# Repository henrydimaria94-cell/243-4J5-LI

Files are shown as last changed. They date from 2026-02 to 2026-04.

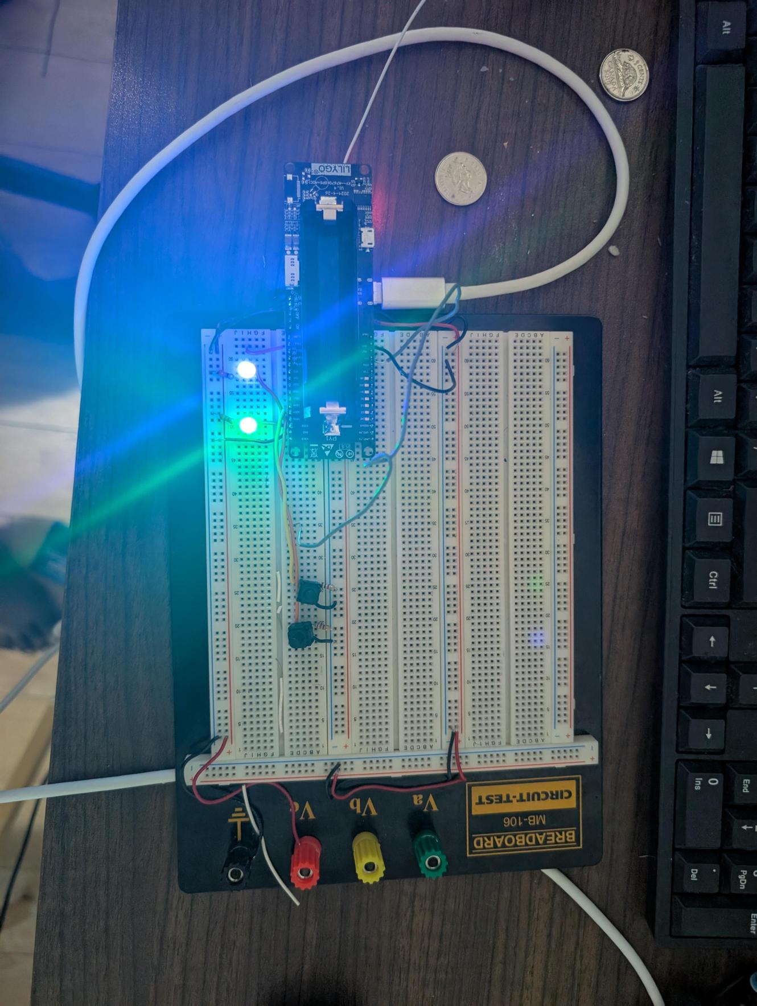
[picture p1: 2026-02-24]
labo/Labo-02/Média (19).jpg

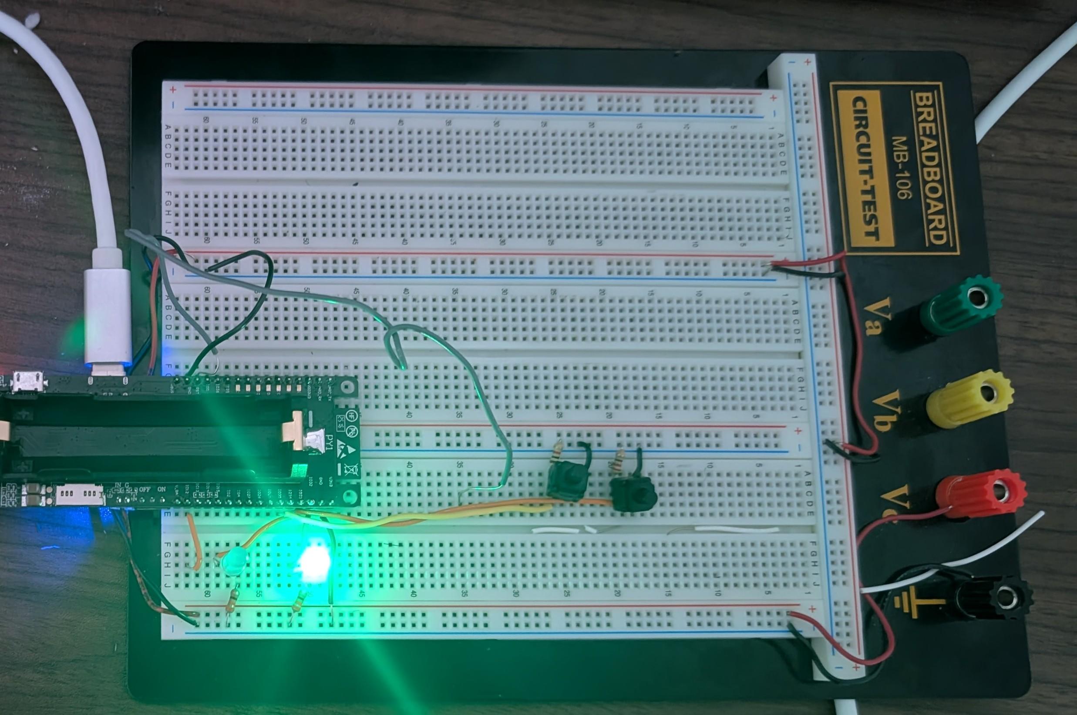
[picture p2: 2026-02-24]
labo/Labo-02/Média (20).jpg

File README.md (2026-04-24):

# Labo 04 — Communication LoRa avec LilyGo T-Beam Supreme

Communication bidirectionnelle LoRa entre deux modules LilyGo T-Beam Supreme S3.  
Le transmetteur envoie la valeur d'un potentiomètre ; le récepteur interroge un LLM via l'API Groq, renvoie la réponse par LoRa et publie les métriques sur un broker MQTT.

## Architecture du système

```
[Transmetteur]                              [Récepteur]
  Potentiomètre                               SX1262 (LoRa)
       │                                           │
  SX1262 (LoRa) ──── 915 MHz / SF9 ──────►  WiFi → API Groq (LLM)
       │                                           │
  OLED SH1106   ◄──── réponse texte ────────  MQTT WebSocket TLS
  LED GPIO 43                                 LED GPIO 43
```

## Matériel requis

| Composant | Quantité |
|---|---|
| LilyGo T-Beam Supreme S3 (SX1262) | 2 |
| Potentiomètre (branché sur GPIO 2) | 1 |

## Structure du projet

```
Labo-04-TP/
├── transmitter/
│   ├── transmitter.ino       # Sketch émetteur LoRa
│   ├── LoRaBoards.h/.cpp     # Abstraction matérielle LilyGo
│   └── utilities.h           # Définitions des broches
│
├── receiver/
│   ├── receiver.ino          # Sketch récepteur LoRa + LLM + MQTT
│   ├── config.example.h      # ← Modèle de configuration
│   ├── config.h              # ← À créer (ignoré par Git)
│   ├── LoRaBoards.h/.cpp
│   └── utilities.h
│
└── llm-t-beam-supreme/       # Sketch autonome test LLM sans LoRa
```

## Installation

### 1. Cloner le dépôt

```bash
git clone <url-du-repo>
```

### 2. Créer le fichier de configuration

```bash
cp receiver/config.example.h receiver/config.h
```

Ouvrez `receiver/config.h` et remplissez vos valeurs :

```cpp
// WiFi personnel
#define WIFI_SECURITY_WPA2_PERSONAL
const char* WIFI_SSID     = "MonReseau";
const char* WIFI_PASSWORD = "MonMotDePasse";

// API Groq — https://console.groq.com
const char* API_KEY = "gsk_...";

// MQTT
const char* MQTT_BROKER = "votre-broker.exemple.com";
const char* MQTT_USER   = "utilisateur";
const char* MQTT_PASS   = "motdepasse";

// Topics — adaptez le préfixe
const char* MQTT_TOPIC_POT     = "prenom-nom/pot";
const char* MQTT_TOPIC_REPONSE = "prenom-nom/reponse";
const char* MQTT_TOPIC_RSSI    = "prenom-nom/rssi";
const char* MQTT_TOPIC_SNR     = "prenom-nom/snr";
```

> `config.h` est listé dans `.gitignore` — il ne sera jamais commité.

### 3. Librairies Arduino requises

Installez via le gestionnaire de librairies Arduino IDE :

| Librairie | Auteur |
|---|---|
| ArduinoJson | Benoit Blanchon |
| U8g2 | olikraus |
| XPowersLib | Lewis He |
| RadioLib | jgromes |
| PubSubClient | Nick O'Leary |

### 4. Sélectionner la carte

**Tools → Board → ESP32S3 Dev Module**

| Paramètre | Valeur |
|---|---|
| USB CDC On Boot | Enabled |
| Flash Size | 16MB |
| PSRAM | OPI PSRAM |

### 5. Téléverser

1. Téléverser `transmitter/transmitter.ino` sur le premier T-Beam.
2. Téléverser `receiver/receiver.ino` sur le second T-Beam.

## Paramètres LoRa

| Paramètre | Valeur |
|---|---|
| Fréquence | 915.0 MHz |
| Bande passante | 125 kHz |
| Spreading Factor | 9 |
| Coding Rate | 7 |
| Sync Word | 0x12 |
| Puissance TX | 14 dBm |
| Préambule | 16 |
| CRC | Activé |

## Format des messages LoRa

**Transmetteur → Récepteur**
```json
{ "pot": 2048 }
```

**Récepteur → Transmetteur**
```
Texte brut — réponse du LLM (max 40 caractères)
```

## Topics MQTT publiés par le récepteur

| Topic | Contenu |
|---|---|
| `{prefix}/pot` | Valeur du potentiomètre (0–4095) |
| `{prefix}/reponse` | Réponse du LLM |
| `{prefix}/rssi` | RSSI LoRa (dBm) |
| `{prefix}/snr` | SNR LoRa (dB) |

## Comportement du transmetteur

- Lecture continue du potentiomètre (GPIO 2, ADC 12 bits, 0–4095)
- Envoi si valeur stable ≥ 400 ms **et** variation > 80 unités depuis le dernier envoi
- Délai minimal de 3 secondes entre deux transmissions
- Attente de la réponse du récepteur (timeout 30 s)
- LED GPIO 43 : 3 flashs rapides à l'envoi, puis fixe selon l'effort (HIGH si pot > 2048)

## Comportement du récepteur

- Réception LoRa par interruption (DIO1)
- Appel API Groq dès réception d'un paquet valide
- Retransmission de la réponse texte au transmetteur
- Publication MQTT sur 4 topics
- Affichage OLED avec retour écran veille après 10 secondes
- LED GPIO 43 : allumée pendant le traitement LLM

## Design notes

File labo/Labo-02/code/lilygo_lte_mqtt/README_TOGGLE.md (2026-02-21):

# Guide : Synchronisation ESP32 ↔ Interface Python

## 🔄 Problème résolu

L'interface Python n'affichait pas les changements d'état des LEDs causés par les boutons physiques car elle ne s'abonnait pas aux topics d'état.

## ✅ Modifications apportées

### 1. Code Arduino (`lilygo_lte_mqtt_toggle.ino`)

#### Nouveaux topics MQTT
```cpp
char LED1_STATE_TOPIC[50];  // {device_id}/led/1/state
char LED2_STATE_TOPIC[50];  // {device_id}/led/2/state
```

#### Variables d'état avec debounce
```cpp
bool led1State = false;
bool led2State = false;
unsigned long lastButton1Press = 0;
unsigned long lastButton2Press = 0;
const unsigned long DEBOUNCE_DELAY = 200;  // 200ms
```

#### Fonction de toggle
```cpp
void checkButtonsForToggle() {
    unsigned long now = millis();
    
    // Bouton 1
    if (digitalRead(BUTTON1_PIN) == LOW) {
        if (now - lastButton1Press > DEBOUNCE_DELAY) {
            lastButton1Press = now;
            led1State = !led1State;
            digitalWrite(LED1_PIN, led1State ? HIGH : LOW);
            const char* state = led1State ? "ON" : "OFF";
            mqttClient.publish(LED1_STATE_TOPIC, state);
        }
    }
    
    // Bouton 2 (même logique)
}
```

### 2. Interface Python (`touch_ui_mqtt.py`)

#### Ajout des topics d'état
```python
self.led1_state_topic = f"{device_id}/led/1/state"
self.led2_state_topic = f"{device_id}/led/2/state"
```

#### Abonnement aux topics d'état
```python
def _on_mqtt_connect(self, client, userdata, flags, rc):
    # ... code existant ...
    client.subscribe(self.led1_state_topic)
    client.subscribe(self.led2_state_topic)
```

#### Synchronisation de l'état
```python
def _on_mqtt_message(self, client, userdata, msg):
    topic = msg.topic
    payload = msg.payload.decode('utf-8', errors='ignore')
    
    # Synchroniser LED1
    if topic == self.led1_state_topic:
        self.led1_state = (payload == "ON")
        self.status_message = f"LED ROUGE: {payload} (ESP32)"
    
    # Synchroniser LED2
    elif topic == self.led2_state_topic:
        self.led2_state = (payload == "ON")
        self.status_message = f"LED VERTE: {payload} (ESP32)"
```

## 📊 Architecture de communication

### Flux de données

```
┌─────────────────┐                    ┌──────────────────┐
│   ESP32 LilyGO  │                    │  Interface Python│
│                 │                    │                  │
│  Bouton 1 (34) ─┼──┐                 │                  │
│  Bouton 2 (35) ─┼──┤                 │                  │
│                 │  │                 │                  │
│  LED 1 (32)  ◄──┼──┤                 │                  │
│  LED 2 (33)  ◄──┼──┘                 │                  │
└────────┬────────┘                    └────────┬─────────┘
         │                                      │
         │  MQTT via WSS (Port 443)            │
         │  ════════════════════════            │
         │                                      │
         ├──► {id}/led/1/state ────────────────┤
         │         (ON/OFF)                     │
         │                                      │
         ├──► {id}/led/2/state ────────────────┤
         │         (ON/OFF)                     │
         │                                      │
         │◄──── {id}/led/1/set ─────────────────┤
         │         (ON/OFF)                     │
         │                                      │
         │◄──── {id}/led/2/set ─────────────────┤
                   (ON/OFF)
```

### Topics MQTT

| Topic | Publisher | Subscriber | Payload | Description |
|---|---|---|---|---|
| `{id}/led/1/set` | Python | ESP32 | `ON` / `OFF` | Commande depuis interface |
| `{id}/led/2/set` | Python | ESP32 | `ON` / `OFF` | Commande depuis interface |
| `{id}/led/1/state` | ESP32 | Python | `ON` / `OFF` | État actuel LED1 |
| `{id}/led/2/state` | ESP32 | Python | `ON` / `OFF` | État actuel LED2 |
| `{id}/button/1/state` | ESP32 | Python | `PRESSED` / `RELEASED` | Événement bouton 1 |
| `{id}/button/2/state` | ESP32 | Python | `PRESSED` / `RELEASED` | Événement bouton 2 |

## 🧪 Test de fonctionnement

### Scénario 1 : Toggle depuis bouton physique
1. **Action** : Appuyer sur Bouton 1 (GPIO 34)
2. **ESP32** :
   - Toggle `led1State` (OFF → ON)
   - Allume LED1 physiquement
   - Publie `{id}/led/1/state = ON`
3. **Interface Python** :
   - Reçoit le message MQTT
   - Met à jour `self.led1_state = True`
   - Affiche "ON" en gros caractères
   - Status : "LED ROUGE: ON (ESP32)"

### Scénario 2 : Commande depuis interface
1. **Action** : Toucher "LED VERTE" dans l'interface
2. **Interface Python** :
   - Toggle `self.led2_state` (OFF → ON)
   - Publie `{id}/led/2/set = ON`
3. **ESP32** :
   - Reçoit la commande
   - Allume LED2 physiquement
   - Met à jour `led2State = true`
   - Confirme avec `{id}/led/2/state = ON`
4. **Interface Python** :
   - Reçoit la confirmation
   - État déjà à jour (pas de changement visuel)

### Scénario 3 : Synchronisation au démarrage
1. **ESP32** démarre avec LEDs éteintes
2. **ESP32** se connecte à MQTT et publie :
   - `{id}/led/1/state = OFF`
   - `{id}/led/2/state = OFF`
3. **Interface Python** reçoit les messages et synchronise l'affichage

## 🐛 Vérification du bon fonctionnement

### Dans le moniteur série de l'ESP32
```
[BTN1 TOGGLE] LED1 -> ON
[BTN1 TOGGLE] LED1 -> OFF
[BTN2 TOGGLE] LED2 -> ON
[LED1] Allumee (ROUGE) - commande distante
```

### Dans l'interface Python (zone MQTT DEBUG)
```
✓ Connecté au broker MQTT
✓ Abonné à esp32-XXXX/led/1/state
✓ Abonné à esp32-XXXX/led/2/state
← esp32-XXXX/led/1/state: ON
🔴 LED1 mise à jour: ON
→ esp32-XXXX/led/2/set: OFF
← esp32-XXXX/led/2/state: OFF
🟢 LED2 mise à jour: OFF
```

## 🔧 Configuration requise

### Fichier `auth.h` (ESP32)
```cpp
#define MQTT_BROKER "mqtt.edxo.ca"
#define MQTT_CLIENT_ID "esp32-XXXX"  // Votre ID unique
#define MQTT_USER "esp_user"
#define MQTT_PASS "votre_mot_de_passe"
#define APN "votre_apn"
// ...
```

### Fichier `mqtt_config.py` (Python)
```python
MQTT_CONFIG = {
    "broker": "mqtt.edxo.ca",
    "port": 443,
    "device_id": "esp32-XXXX",  # Doit correspondre à MQTT_CLIENT_ID
    "username": "esp_user",
    "password": "votre_mot_de_passe"
}
```

## ⚠️ Points d'attention

1. **Device ID identique** : Le `device_id` dans Python doit correspondre au `MQTT_CLIENT_ID` de l'ESP32
2. **Connexion WSS** : Port 443 avec WebSocket Secure
3. **Debounce** : 200ms pour éviter les rebonds des boutons
4. **Pull-up interne** : Les boutons utilisent `INPUT_PULLUP` (LOW = pressé)
5. **Synchronisation bidirectionnelle** : Les deux interfaces publient ET s'abonnent aux états

## 📝 Fichiers modifiés

- ✅ `lilygo_lte_mqtt_toggle.ino` (nouveau fichier)
- ✅ `touch_ui_mqtt.py` (modifications)
- ✅ Code original `lilygo_lte_mqtt.ino` (conservé intact)

## 🚀 Démarrage rapide

1. **Téléverser** `lilygo_lte_mqtt_toggle.ino` sur l'ESP32
2. **Vérifier** les connexions :
   - Bouton 1 → GPIO 34
   - Bouton 2 → GPIO 35
   - LED 1 → GPIO 32 (rouge)
   - LED 2 → GPIO 33 (verte)
3. **Lancer** l'interface Python :
   ```bash
   cd /home/henridumont/243-4J5-LI/labo/Labo-02/led-control
   python3 touch_ui_mqtt.py
   ```
4. **Tester** :
   - Appuyer sur les boutons physiques
   - Toucher l'écran pour contrôler les LEDs
   - Observer la synchronisation dans les deux sens

## 🎯 Résultat attendu

- ✅ Appui sur bouton physique → LED change + Interface se met à jour
- ✅ Touch sur interface → LED change + État confirmé par ESP32
- ✅ Messages MQTT visibles dans la zone DEBUG
- ✅ Pas de désynchronisation entre ESP32 et Python

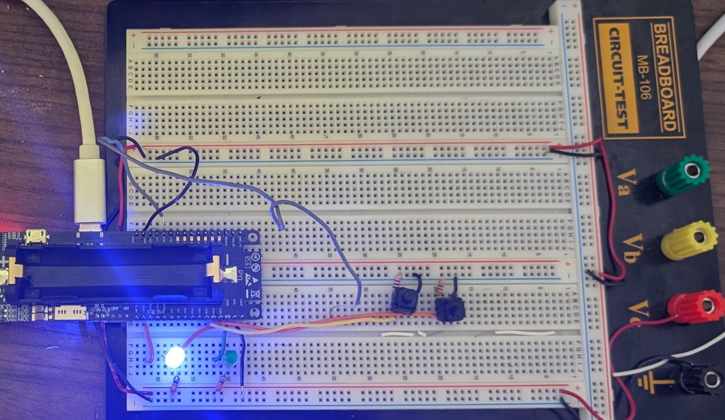
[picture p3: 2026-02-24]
labo/Labo-02/Média (18).jpg

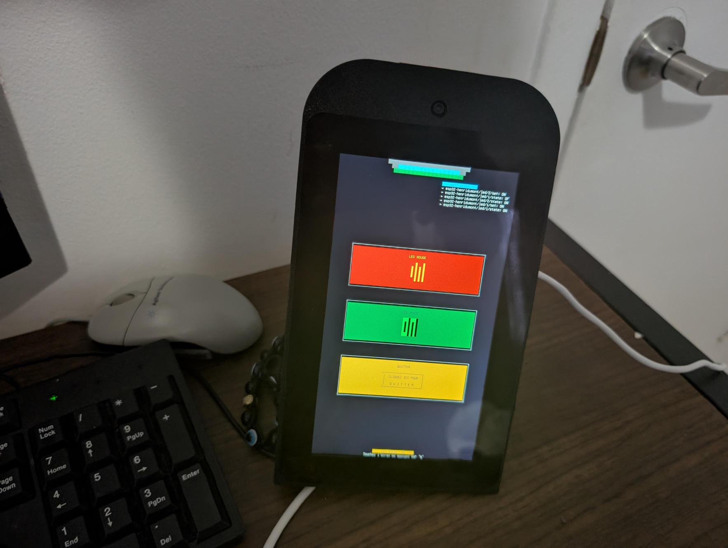
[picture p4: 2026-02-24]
labo/Labo-02/Média (17).jpg

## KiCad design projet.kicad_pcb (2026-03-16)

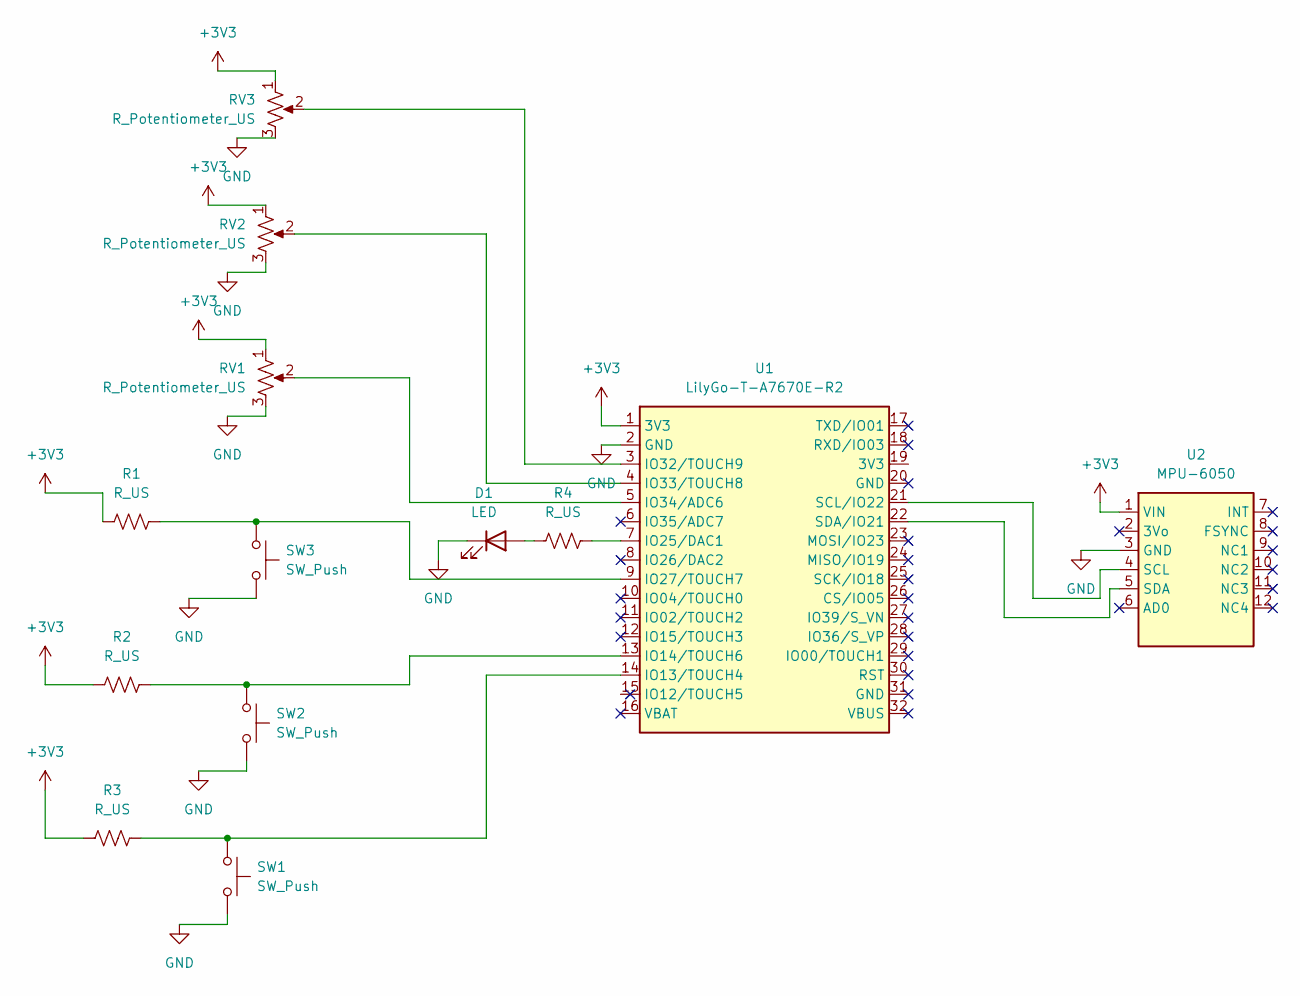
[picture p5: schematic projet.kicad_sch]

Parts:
D1: LED; LED_D5.0mm
R1, R2, R3, R4: R_US; R_Axial_DIN0207_L6.3mm_D2.5mm_P7.62mm_Horizontal
RV1, RV2, RV3: R_Potentiometer_US; Potentiometer_Bourns_3386P_Vertical
SW1, SW2, SW3: SW_Push; SW_B3WN-600x_OMR
U1: LilyGo-T-A7670E-R2; LilyGO_T-A7670E-R2
U2: MPU-6050; MPU-6050_Breakout

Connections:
+3V3: R1.1, R2.1, R3.1, RV1.1, RV2.1, RV3.1, U1.1 (3V3), U2.1 (VIN)
GND: D1.1 (K), RV1.3, RV2.3, RV3.3, SW1.2, SW2.2, SW3.2, U1.2 (GND), U2.3 (GND)
unnamed: D1.2 (A), R4.1
unnamed: R3.2, SW1.1, U1.14 (IO13/TOUCH4)
unnamed: R2.2, SW2.1, U1.13 (IO14/TOUCH6)
unnamed: R4.2, U1.7 (IO25/DAC1)
unnamed: R1.2, SW3.1, U1.9 (IO27/TOUCH7)
unnamed: RV3.2, U1.3 (IO32/TOUCH9)
unnamed: RV2.2, U1.4 (IO33/TOUCH8)
unnamed: RV1.2, U1.5 (IO34/ADC6)
unnamed: U1.21 (SCL/IO22), U2.4 (SCL)
unnamed: U1.22 (SDA/IO21), U2.5 (SDA)

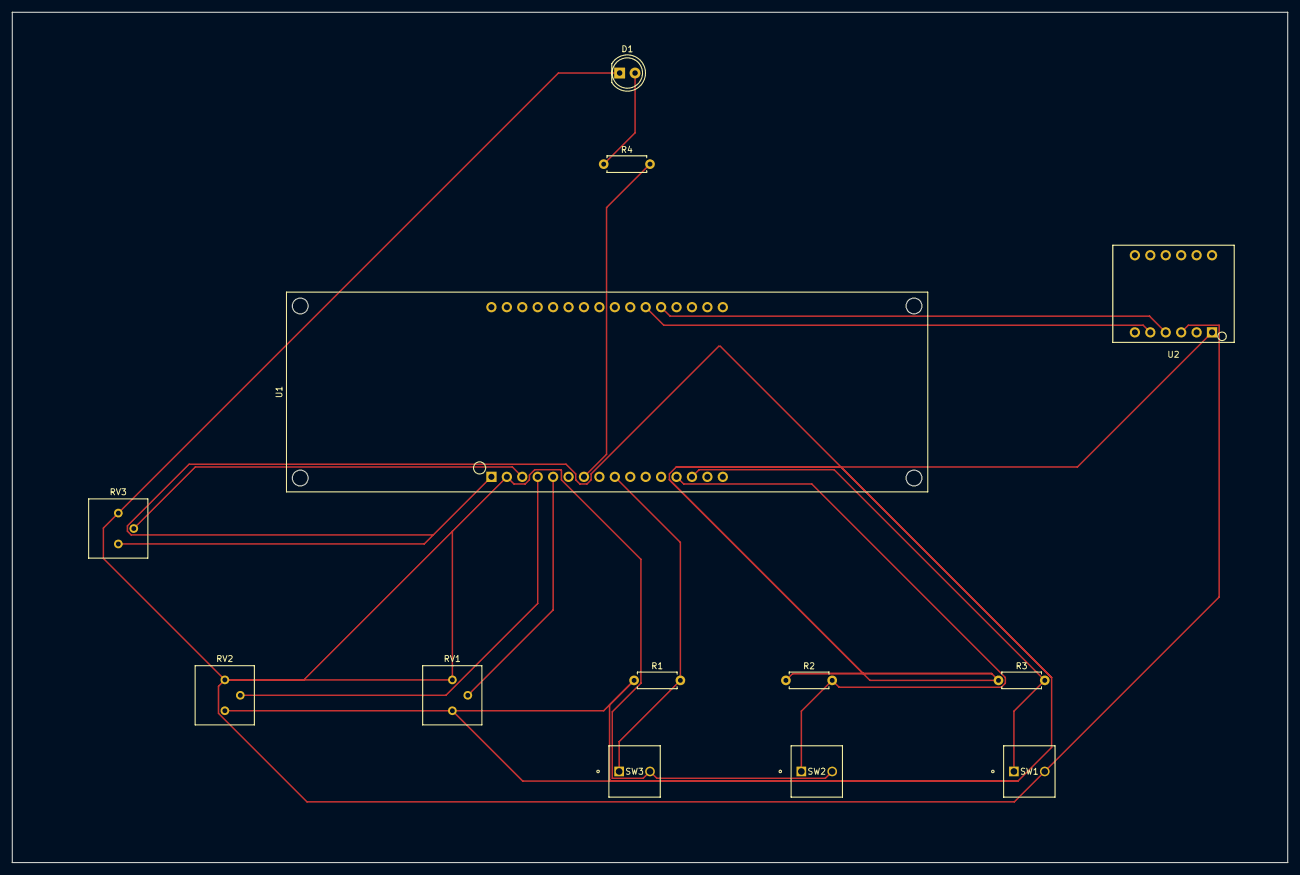
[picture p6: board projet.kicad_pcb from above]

Board: 2 copper layers, 210.0 x 140.0 mm, 13 parts (0 on the bottom side), 12 nets.

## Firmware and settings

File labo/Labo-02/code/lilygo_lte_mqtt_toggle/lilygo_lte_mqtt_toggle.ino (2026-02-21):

// LilyGO T-SIM A7670G - Version avec TOGGLE des LEDs par boutons
// Basé sur lilygo_lte_mqtt.ino avec ajout de la fonctionnalité de toggle
// Les boutons permettent maintenant de basculer l'état des LEDs localement
// et de publier l'état sur MQTT

#define TINY_GSM_MODEM_SIM7600
#define TINY_GSM_RX_BUFFER 1024

#include <TinyGsmClient.h>
#include <PubSubClient.h>

// ESP_SSLClient configuration
#define ENABLE_DEBUG
#define ENABLE_ERROR_STRING
#define DEBUG_PORT Serial
#define SSLCLIENT_INSECURE_ONLY

#include <ESP_SSLClient.h>
#include <mbedtls/base64.h>

#include "auth.h"

// ====== CONFIG MODEM A7670G ======
#define MODEM_TX 26
#define MODEM_RX 27
#define MODEM_PWRKEY 4
#define MODEM_DTR 12
#define MODEM_RI 13
#define MODEM_FLIGHT 25
#define MODEM_STATUS 0

#define SD_MISO 2
#define SD_MOSI 15
#define SD_SCLK 14
#define SD_CS 13

// ====== CONFIG MQTT/WSS ======
const char* MQTT_HOST = MQTT_BROKER;
const int   MQTT_WSS_PORT = 443;
const char* MQTT_PATH = "/";

// Topics MQTT
char BUTTON1_STATE_TOPIC[50];  // {device_id}/button/1/state (PRESSED/RELEASED)
char BUTTON2_STATE_TOPIC[50];  // {device_id}/button/2/state (PRESSED/RELEASED)
char LED1_SET_TOPIC[50];       // {device_id}/led/1/set (commandes depuis l'interface)
char LED2_SET_TOPIC[50];       // {device_id}/led/2/set (commandes depuis l'interface)
char LED1_STATE_TOPIC[50];     // {device_id}/led/1/state (état ON/OFF publié par ESP32)
char LED2_STATE_TOPIC[50];     // {device_id}/led/2/state (état ON/OFF publié par ESP32)

// --- Configuration des broches (Pins) ---
const int LED1_PIN = 32;
const int LED2_PIN = 33;
const int BUTTON1_PIN = 34;
const int BUTTON2_PIN = 35;

// ====== VARIABLES GLOBALES POUR LE TOGGLE ======
bool led1State = false;              // État actuel de LED1
bool led2State = false;              // État actuel de LED2
unsigned long lastButton1Press = 0; // Timestamp du dernier appui bouton 1
unsigned long lastButton2Press = 0; // Timestamp du dernier appui bouton 2
const unsigned long DEBOUNCE_DELAY = 200;  // Délai anti-rebond (200ms)

// Serial pour le modem
HardwareSerial SerialAT(1);

// ============================================================================
// CLASSE WRAPPER WEBSOCKET POUR PUBSUBCLIENT
// ============================================================================

class WebSocketClient : public Client {
private:
  ESP_SSLClient* _sslClient;
  bool _wsConnected;

  // Buffer pour les données reçues
  uint8_t _rxBuffer[512];
  size_t _rxBufferLen;
  size_t _rxBufferPos;

  String generateWebSocketKey() {
    uint8_t key[16];
    for(int i = 0; i < 16; i++) {
      key[i] = random(0, 256);
    }
    size_t olen;
    unsigned char output[64];
    mbedtls_base64_encode(output, sizeof(output), &olen, key, 16);
    return String((char*)output);
  }

  bool readWebSocketFrame() {
    if (!_sslClient->available()) return false;

    uint8_t byte1 = _sslClient->read();
    if (!_sslClient->available()) return false;
    uint8_t byte2 = _sslClient->read();

    uint8_t opcode = byte1 & 0x0F;
    bool masked = (byte2 & 0x80) != 0;
    size_t payloadLen = byte2 & 0x7F;

    if (payloadLen == 126) {
      if (_sslClient->available() < 2) return false;
      payloadLen = (_sslClient->read() << 8) | _sslClient->read();
    } else if (payloadLen == 127) {
      if (_sslClient->available() < 8) return false;
      payloadLen = 0;
      for(int i = 0; i < 8; i++) {
        payloadLen = (payloadLen << 8) | _sslClient->read();
      }
    }

    uint8_t mask[4] = {0};
    if (masked) {
      if (_sslClient->available() < 4) return false;
      for(int i = 0; i < 4; i++) {
        mask[i] = _sslClient->read();
      }
    }

    if (opcode == 0x01 || opcode == 0x02) { // Text ou Binary
      if (_sslClient->available() < payloadLen) return false;

      _rxBufferLen = payloadLen < sizeof(_rxBuffer) ? payloadLen : sizeof(_rxBuffer);
      for(size_t i = 0; i < _rxBufferLen; i++) {
        _rxBuffer[i] = _sslClient->read();
        if (masked) _rxBuffer[i] ^= mask[i % 4];
      }
      _rxBufferPos = 0;
      return true;
    }
    else if (opcode == 0x08) { // Close
      Serial.println("[WSS] Serveur a ferme la connexion");
      _wsConnected = false;
      return false;
    }
    else if (opcode == 0x09) { // Ping
      uint8_t pong[2] = {0x8A, 0x00};
      _sslClient->write(pong, 2);
      return false;
    }

    return false;
  }

public:
  WebSocketClient(ESP_SSLClient* sslClient) {
    _sslClient = sslClient;
    _wsConnected = false;
    _rxBufferLen = 0;
    _rxBufferPos = 0;
  }

  int connect(IPAddress ip, uint16_t port) { return 0; }
  int connect(const char *host, uint16_t port) {
    Serial.println("[WSS] Connexion SSL...");

    if (!_sslClient->connect(host, port)) {
      Serial.println("[WSS] Echec connexion SSL");
      return 0;
    }

    Serial.println("[WSS] SSL connecte, envoi handshake WebSocket...");
    String wsKey = generateWebSocketKey();

    _sslClient->print("GET ");
    _sslClient->print(MQTT_PATH);
    _sslClient->print(" HTTP/1.1\r\nHost: ");
    _sslClient->print(host);
    _sslClient->print("\r\nUpgrade: websocket\r\n");
    _sslClient->print("Connection: Upgrade\r\n");
    _sslClient->print("Sec-WebSocket-Key: ");
    _sslClient->print(wsKey);
    _sslClient->print("\r\nSec-WebSocket-Protocol: mqtt\r\n");
    _sslClient->print("Sec-WebSocket-Version: 13\r\n\r\n");

    unsigned long timeout = millis();
    while (!_sslClient->available() && millis() - timeout < 5000) {
      delay(10);
    }

    if (!_sslClient->available()) {
      Serial.println("[WSS] Timeout handshake");
      return 0;
    }

    String response = "";
    while (_sslClient->available()) {
      char c = _sslClient->read();
      response += c;
      if (response.endsWith("\r\n\r\n")) break;
    }

    if (response.indexOf("101") > 0 && response.indexOf("Switching Protocols") > 0) {
      Serial.println("[WSS] Handshake WebSocket reussi!");
      _wsConnected = true;
      return 1;
    } else {
      Serial.println("[WSS] Handshake WebSocket echoue");
      return 0;
    }
  }

  size_t write(uint8_t b) {
    return write(&b, 1);
  }

  size_t write(const uint8_t *buf, size_t size) {
    if (!_wsConnected) return 0;

    // Frame WebSocket binaire avec masque
    uint8_t header[14];
    int headerLen = 2;

    header[0] = 0x82; // FIN + Binary frame

    if (size < 126) {
      header[1] = 0x80 | size;
    } else if (size < 65536) {
      header[1] = 0x80 | 126;
      header[2] = (size >> 8) & 0xFF;
      header[3] = size & 0xFF;
      headerLen = 4;
    } else {
      header[1] = 0x80 | 127;
      for(int i = 0; i < 8; i++) header[2 + i] = 0;
      header[6] = (size >> 24) & 0xFF;
      header[7] = (size >> 16) & 0xFF;
      header[8] = (size >> 8) & 0xFF;
      header[9] = size & 0xFF;
      headerLen = 10;
    }

    // Masque aléatoire
    uint8_t mask[4];
    for(int i = 0; i < 4; i++) {
      mask[i] = random(0, 256);
      header[headerLen + i] = mask[i];
    }
    headerLen += 4;

    _sslClient->write(header, headerLen);

    for(size_t i = 0; i < size; i++) {
      uint8_t maskedByte = buf[i] ^ mask[i % 4];
      _sslClient->write(&maskedByte, 1);
    }

    return size;
  }

  int available() {
    // D'abord vérifier le buffer
    if (_rxBufferPos < _rxBufferLen) {
      return _rxBufferLen - _rxBufferPos;
    }

    // Sinon essayer de lire une nouvelle frame
    if (_sslClient->available()) {
      if (readWebSocketFrame()) {
        return _rxBufferLen - _rxBufferPos;
      }
    }

    return 0;
  }

  int read() {
    if (_rxBufferPos < _rxBufferLen) {
      return _rxBuffer[_rxBufferPos++];
    }

    if (_sslClient->available()) {
      if (readWebSocketFrame() && _rxBufferPos < _rxBufferLen) {
        return _rxBuffer[_rxBufferPos++];
      }
    }

    return -1;
  }

  int read(uint8_t *buf, size_t size) {
    size_t count = 0;
    while (count < size) {
      int c = read();
      if (c < 0) break;
      buf[count++] = (uint8_t)c;
    }
    return count;
  }

  int peek() {
    if (_rxBufferPos < _rxBufferLen) {
      return _rxBuffer[_rxBufferPos];
    }
    return -1;
  }

  void flush() {
    _sslClient->flush();
  }

  void stop() {
    _wsConnected = false;
    _sslClient->stop();
  }

  uint8_t connected() {
    return _wsConnected && _sslClient->connected();
  }

  operator bool() {
    return _wsConnected;
  }
};

// ============================================================================
// CLIENTS ET MQTT
// ============================================================================

TinyGsm modem(SerialAT);
TinyGsmClient gsmClient(modem, 0);
ESP_SSLClient sslClient;
WebSocketClient wsClient(&sslClient);
PubSubClient mqttClient(wsClient);

// État (conservé pour compatibilité avec l'ancien code)
long lastButtonCheck = 0;
int lastButton1State = HIGH;
int lastButton2State = HIGH;
unsigned long lastGprsCheck = 0;
const unsigned long GPRS_CHECK_INTERVAL = 30000;

// ============================================================================
// CALLBACK MQTT
// ============================================================================

void mqttCallback(char* topic, byte* payload, unsigned int length) {
  String msg = "";
  for (unsigned int i = 0; i < length; i++) {
    msg += (char)payload[i];
  }

  Serial.print("[MQTT] <- ");
  Serial.print(topic);
  Serial.print(" = ");
  Serial.println(msg);

  // Commandes depuis l'interface Python
  if (strcmp(topic, LED1_SET_TOPIC) == 0) {
    if (msg == "ON") {
      led1State = true;
      digitalWrite(LED1_PIN, HIGH);
      Serial.println("[LED1] Allumee (ROUGE) - commande distante");
      // Publier l'état confirmé
      mqttClient.publish(LED1_STATE_TOPIC, "ON");
    } else if (msg == "OFF") {
      led1State = false;
      digitalWrite(LED1_PIN, LOW);
      Serial.println("[LED1] Eteinte - commande distante");
      // Publier l'état confirmé
      mqttClient.publish(LED1_STATE_TOPIC, "OFF");
    }
  }
  else if (strcmp(topic, LED2_SET_TOPIC) == 0) {
    if (msg == "ON") {
      led2State = true;
      digitalWrite(LED2_PIN, HIGH);
      Serial.println("[LED2] Allumee (VERTE) - commande distante");
      // Publier l'état confirmé
      mqttClient.publish(LED2_STATE_TOPIC, "ON");
    } else if (msg == "OFF") {
      led2State = false;
      digitalWrite(LED2_PIN, LOW);
      Serial.println("[LED2] Eteinte - commande distante");
      // Publier l'état confirmé
      mqttClient.publish(LED2_STATE_TOPIC, "OFF");
    }
  }
}

// ============================================================================
// FONCTIONS MODEM
// ============================================================================

void modemPowerOn() {
  Serial.println("[MODEM] Allumage du modem...");
  pinMode(MODEM_PWRKEY, OUTPUT);
  digitalWrite(MODEM_PWRKEY, HIGH);
  delay(100);
  digitalWrite(MODEM_PWRKEY, LOW);
  delay(1000);
  digitalWrite(MODEM_PWRKEY, HIGH);
  delay(3000);
  Serial.println("[MODEM] Modem allume");
}

bool initModem() {
  Serial.println("[MODEM] Initialisation...");

  SerialAT.begin(115200, SERIAL_8N1, MODEM_RX, MODEM_TX);
  delay(3000);

  if (!modem.restart()) {
    Serial.println("[MODEM] Echec du redemarrage");
    return false;
  }

  String modemInfo = modem.getModemInfo();
  Serial.print("[MODEM] Info: ");
  Serial.println(modemInfo);

  String imei = modem.getIMEI();
  Serial.print("[MODEM] IMEI: ");
  Serial.println(imei);

  Serial.print("[MQTT] Device ID: ");
  Serial.println(MQTT_CLIENT_ID);

  // Configuration des topics MQTT
  snprintf(LED1_SET_TOPIC, sizeof(LED1_SET_TOPIC), "%s/led/1/set", MQTT_CLIENT_ID);
  snprintf(LED2_SET_TOPIC, sizeof(LED2_SET_TOPIC), "%s/led/2/set", MQTT_CLIENT_ID);
  snprintf(LED1_STATE_TOPIC, sizeof(LED1_STATE_TOPIC), "%s/led/1/state", MQTT_CLIENT_ID);
  snprintf(LED2_STATE_TOPIC, sizeof(LED2_STATE_TOPIC), "%s/led/2/state", MQTT_CLIENT_ID);
  snprintf(BUTTON1_STATE_TOPIC, sizeof(BUTTON1_STATE_TOPIC), "%s/button/1/state", MQTT_CLIENT_ID);
  snprintf(BUTTON2_STATE_TOPIC, sizeof(BUTTON2_STATE_TOPIC), "%s/button/2/state", MQTT_CLIENT_ID);

  Serial.println("[TOPICS MQTT]");
  Serial.print("  LED1 Set:   "); Serial.println(LED1_SET_TOPIC);
  Serial.print("  LED1 State: "); Serial.println(LED1_STATE_TOPIC);
  Serial.print("  LED2 Set:   "); Serial.println(LED2_SET_TOPIC);
  Serial.print("  LED2 State: "); Serial.println(LED2_STATE_TOPIC);
  Serial.print("  BTN1 State: "); Serial.println(BUTTON1_STATE_TOPIC);
  Serial.print("  BTN2 State: "); Serial.println(BUTTON2_STATE_TOPIC);

  Serial.println("[MODEM] Initialise");
  return true;
}

bool connectToNetwork() {
  Serial.println("[NETWORK] Configuration de l'APN...");

  modem.sendAT("+CGDCONT=1,\"IP\",\"", APN, "\"");
  if (modem.waitResponse() != 1) {
    Serial.println("[NETWORK] Echec de configuration APN");
  } else {
    Serial.println("[NETWORK] APN configure");
  }

  Serial.println("[NETWORK] Connexion au reseau cellulaire...");

  if (!modem.waitForNetwork(60000L)) {
    Serial.println("[NETWORK] Echec de connexion au reseau");
    return false;
  }

  String operator_name = modem.getOperator();
  Serial.print("[NETWORK] Operateur: ");
  Serial.println(operator_name);

  int signalQuality = modem.getSignalQuality();
  Serial.print("[NETWORK] Signal: ");
  Serial.print(signalQuality);
  Serial.println(" dBm");

  Serial.println("[GPRS] Connexion GPRS...");
  if (!modem.gprsConnect(APN, APN_USER, APN_PASS)) {
    Serial.println("[GPRS] Echec de connexion GPRS");
    return false;
  }

  if (!modem.isGprsConnected()) {
    Serial.println("[GPRS] GPRS non connecte");
    return false;
  }

  IPAddress ip = modem.localIP();
  Serial.print("[GPRS] IP: ");
  Serial.println(ip);
  Serial.println("[GPRS] Connecte");

  return true;
}

// ============================================================================
// FONCTION TOGGLE DES LEDS PAR BOUTONS (NOUVELLE FONCTIONNALITÉ)
// ============================================================================

void checkButtonsForToggle() {
  unsigned long now = millis();

  // Ne vérifier que si on est connecté à MQTT
  if (!mqttClient.connected()) return;

  // ===== BOUTON 1 -> Toggle LED1 =====
  if (digitalRead(BUTTON1_PIN) == LOW) {  // Bouton pressé (pull-up actif)
    if (now - lastButton1Press > DEBOUNCE_DELAY) {
      lastButton1Press = now;
      
      // Toggle de l'état
      led1State = !led1State;
      
      // Appliquer physiquement
      digitalWrite(LED1_PIN, led1State ? HIGH : LOW);
      
      // Publier l'état sur MQTT
      const char* state = led1State ? "ON" : "OFF";
      mqttClient.publish(LED1_STATE_TOPIC, state);
      
      // Log dans la console série
      Serial.print("[BTN1 TOGGLE] LED1 -> ");
      Serial.println(state);
    }
  }

  // ===== BOUTON 2 -> Toggle LED2 =====
  if (digitalRead(BUTTON2_PIN) == LOW) {  // Bouton pressé (pull-up actif)
    if (now - lastButton2Press > DEBOUNCE_DELAY) {
      lastButton2Press = now;
      
      // Toggle de l'état
      led2State = !led2State;
      
      // Appliquer physiquement
      digitalWrite(LED2_PIN, led2State ? HIGH : LOW);
      
      // Publier l'état sur MQTT
      const char* state = led2State ? "ON" : "OFF";
      mqttClient.publish(LED2_STATE_TOPIC, state);
      
      // Log dans la console série
      Serial.print("[BTN2 TOGGLE] LED2 -> ");
      Serial.println(state);
    }
  }
}

// ============================================================================
// FONCTION DE DÉTECTION PRESSED/RELEASED (CODE ORIGINAL - OPTIONNEL)
// ============================================================================

void checkButtons() {
  long now = millis();

  if (now - lastButtonCheck < 100) {
    return;
  }
  lastButtonCheck = now;

  if (!mqttClient.connected()) return;

  // Publication des événements PRESSED/RELEASED (si nécessaire pour l'interface)
  int button1State = digitalRead(BUTTON1_PIN);
  if (button1State != lastButton1State) {
    lastButton1State = button1State;
    const char* state = (button1State == LOW) ? "PRESSED" : "RELEASED";
    mqttClient.publish(BUTTON1_STATE_TOPIC, state);
    Serial.print("[BTN1] -> ");
    Serial.println(state);
  }

  int button2State = digitalRead(BUTTON2_PIN);
  if (button2State != lastButton2State) {
    lastButton2State = button2State;
    const char* state = (button2State == LOW) ? "PRESSED" : "RELEASED";
    mqttClient.publish(BUTTON2_STATE_TOPIC, state);
    Serial.print("[BTN2] -> ");
    Serial.println(state);
  }
}

bool reconnectMQTT() {
  Serial.println("[MQTT] Connexion au broker...");

  if (mqttClient.connect(MQTT_CLIENT_ID, MQTT_USER, MQTT_PASS)) {
    Serial.println("[MQTT] Connecte!");

    // Souscription aux topics de commande
    mqttClient.subscribe(LED1_SET_TOPIC);
    mqttClient.subscribe(LED2_SET_TOPIC);
    Serial.println("[MQTT] Souscriptions envoyees");

    // Publier l'état initial des LEDs
    mqttClient.publish(LED1_STATE_TOPIC, led1State ? "ON" : "OFF");
    mqttClient.publish(LED2_STATE_TOPIC, led2State ? "ON" : "OFF");
    Serial.println("[MQTT] Etats initiaux publies");

    return true;
  }

  Serial.print("[MQTT] Echec, code: ");
  Serial.println(mqttClient.state());
  return false;
}

// ============================================================================
// SETUP
// ============================================================================

void setup() {
  Serial.begin(115200);
  delay(2000);

  Serial.println();
  Serial.println("=== LilyGo T-SIM A7670G - MQTT avec TOGGLE des LEDs ===");
  Serial.println();

  // Configuration des GPIO
  pinMode(LED1_PIN, OUTPUT);
  pinMode(LED2_PIN, OUTPUT);
  pinMode(BUTTON1_PIN, INPUT_PULLUP);
  pinMode(BUTTON2_PIN, INPUT_PULLUP);

  // États initiaux
  digitalWrite(LED1_PIN, LOW);
  digitalWrite(LED2_PIN, LOW);
  led1State = false;
  led2State = false;

  modemPowerOn();

  if (!initModem()) {
    Serial.println("[ERREUR] Impossible d'initialiser le modem");
    while (true) {
      digitalWrite(LED1_PIN, !digitalRead(LED1_PIN));
      delay(200);
    }
  }

  if (!connectToNetwork()) {
    Serial.println("[ERREUR] Impossible de se connecter au reseau");
    while (true) {
      digitalWrite(LED1_PIN, !digitalRead(LED1_PIN));
      delay(500);
    }
  }

  // Configurer ESP_SSLClient
  Serial.println("[SSL] Configuration du client SSL...");
  sslClient.setClient(&gsmClient);
  sslClient.setInsecure();
  sslClient.setBufferSizes(2048, 1024);
  sslClient.setDebugLevel(1);

  // Configurer MQTT
  mqttClient.setServer(MQTT_HOST, MQTT_WSS_PORT);
  mqttClient.setCallback(mqttCallback);
  mqttClient.setKeepAlive(60);

  // Connexion WebSocket et MQTT
  if (!wsClient.connect(MQTT_HOST, MQTT_WSS_PORT)) {
    Serial.println("[ERREUR] Impossible de se connecter via WebSocket");
    while (true) {
      digitalWrite(LED1_PIN, !digitalRead(LED1_PIN));
      delay(1000);
    }
  }

  if (!reconnectMQTT()) {
    Serial.println("[ERREUR] Impossible de se connecter au broker MQTT");
    while (true) {
      digitalWrite(LED1_PIN, !digitalRead(LED1_PIN));
      delay(1000);
    }
  }

  Serial.println();
  Serial.println("=== Systeme pret ===");
  Serial.println("  Bouton 1 (GPIO34) -> Toggle LED1 (GPIO32 - Rouge)");
  Serial.println("  Bouton 2 (GPIO35) -> Toggle LED2 (GPIO33 - Verte)");
  Serial.println();

  // Animation de démarrage
  for (int i = 0; i < 3; i++) {
    digitalWrite(LED1_PIN, HIGH);
    digitalWrite(LED2_PIN, HIGH);
    delay(200);
    digitalWrite(LED1_PIN, LOW);
    digitalWrite(LED2_PIN, LOW);
    delay(200);
  }
}

// ============================================================================
// LOOP
// ============================================================================

void loop() {
  unsigned long now = millis();

  // Vérifier la connexion GPRS
  if (now - lastGprsCheck > GPRS_CHECK_INTERVAL) {
    lastGprsCheck = now;

    if (!modem.isGprsConnected()) {
      Serial.println("[GPRS] Connexion perdue");

      if (connectToNetwork()) {
        if (wsClient.connect(MQTT_HOST, MQTT_WSS_PORT)) {
          reconnectMQTT();
        }
      }
    }
  }

  // Maintenir la connexion MQTT
  if (!mqttClient.connected()) {
    reconnectMQTT();
  }

  mqttClient.loop();

  // ===== NOUVELLE FONCTION : Vérifier les boutons pour le toggle =====
  checkButtonsForToggle();

  // ===== OPTIONNEL : Publier PRESSED/RELEASED (si nécessaire) =====
  // Décommenter la ligne suivante si vous voulez aussi publier les événements PRESSED/RELEASED
  // checkButtons();

  delay(10);
}

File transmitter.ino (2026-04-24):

#define T_BEAM_S3_SUPREME_SX1262

#include "LoRaBoards.h"
#include <RadioLib.h>
#include <ArduinoJson.h>

SX1262 radio = new Module(RADIO_CS_PIN, RADIO_DIO1_PIN, RADIO_RST_PIN, RADIO_BUSY_PIN);

#define POT_PIN   2
#define LED_PIN   43

#define LORA_FREQ      915.0
#define LORA_BW        125.0
#define LORA_SF        9
#define LORA_CR        7
#define LORA_SYNC      0x12
#define LORA_POWER     14
#define LORA_PREAMBLE  16

#define STABILITY_MS      400
#define COOLDOWN_MS       3000
#define HYSTERESIS        80
#define RESPONSE_TIMEOUT  30000

volatile bool rxFlag = false;
void IRAM_ATTR onRx() { rxFlag = true; }

enum TxState { STATE_IDLE, STATE_WAITING };
TxState txState = STATE_IDLE;

int  lastSentPot  = -1000;
int  prevPot      = -1;
int  activePot    = 0;
uint32_t stableStart  = 0;
uint32_t lastSendTime = 0;
uint32_t rxDeadline   = 0;

// ---- Helpers ---------------------------------------------------------

void ledFlash(int n) {
    for (int i = 0; i < n; i++) {
        digitalWrite(LED_PIN, HIGH); delay(80);
        digitalWrite(LED_PIN, LOW);  delay(80);
    }
}

void drawWrap(const String& txt, uint8_t y0, uint8_t lineH = 13) {
    if (!disp) return;
    uint8_t x = 0, y = y0;
    const uint8_t spW = disp->getUTF8Width(" ");
    String word;
    for (int i = 0; i <= (int)txt.length(); i++) {
        char c = (i < (int)txt.length()) ? txt[i] : ' ';
        if (c == ' ' || c == '\n') {
            if (word.length()) {
                uint16_t w = disp->getUTF8Width(word.c_str());
                if (x + w > 128) { x = 0; y += lineH; }
                if (y <= 64) disp->drawUTF8(x, y, word.c_str());
                x += w + spW;
                word = "";
            }
        } else {
            word += c;
        }
    }
}

void showIdle(int pot) {
    if (!disp) return;
    disp->clearBuffer();
    disp->setFont(u8g2_font_fur11_tf);
    disp->drawUTF8(0, 13, "Pot:");
    disp->drawUTF8(36, 13, String(pot).c_str());
    int bw = map(pot, 0, 4095, 0, 126);
    disp->drawFrame(1, 20, 126, 10);
    disp->drawBox(1, 20, bw, 10);
    disp->sendBuffer();
}

void showWaiting(int pot) {
    if (!disp) return;
    disp->clearBuffer();
    disp->setFont(u8g2_font_fur11_tf);
    disp->drawUTF8(0, 16, ("Envoi: " + String(pot)).c_str());
    disp->drawUTF8(0, 38, "Attente coach...");
    disp->sendBuffer();
}

void showAnswer(const String& resp, int pot) {
    if (!disp) return;
    disp->clearBuffer();
    disp->setFont(u8g2_font_fur11_tf);
    disp->drawUTF8(0, 13, "Coach:");
    drawWrap(resp, 30);
    disp->sendBuffer();
}

// ---- Setup -----------------------------------------------------------

void setup() {
    setupBoards();

    analogReadResolution(12);
    pinMode(POT_PIN, INPUT);
    pinMode(LED_PIN, OUTPUT);
    digitalWrite(LED_PIN, LOW);

    int err = radio.begin();
    if (err != RADIOLIB_ERR_NONE) {
        Serial.printf("[LoRa] init failed: %d\n", err);
        if (disp) {
            disp->clearBuffer();
            disp->setFont(u8g2_font_fur11_tf);
            disp->drawStr(0, 32, "LoRa ERREUR");
            disp->sendBuffer();
        }
        while (true) delay(500);
    }

    radio.setFrequency(LORA_FREQ);
    radio.setBandwidth(LORA_BW);
    radio.setSpreadingFactor(LORA_SF);
    radio.setCodingRate(LORA_CR);
    radio.setSyncWord(LORA_SYNC);
    radio.setOutputPower(LORA_POWER);
    radio.setPreambleLength(LORA_PREAMBLE);
    radio.setCRC(true);
    radio.setDio1Action(onRx);

    printResult(true);

    if (disp) {
        disp->clearBuffer();
        disp->setFont(u8g2_font_fur11_tf);
        disp->drawUTF8(14, 32, "Transmetteur");
        disp->sendBuffer();
        delay(1500);
    }

    stableStart = millis();
    prevPot = analogRead(POT_PIN);
}

// ---- Loop ------------------------------------------------------------

void loop() {
    int pot = analogRead(POT_PIN);

    if (abs(pot - prevPot) > 20) {
        prevPot = pot;
        stableStart = millis();
    }

    bool stable   = (millis() - stableStart) >= STABILITY_MS;
    bool diff     = abs(pot - lastSentPot) > HYSTERESIS;
    bool cooldown = (millis() - lastSendTime) >= COOLDOWN_MS;

    // ── IDLE ──────────────────────────────────────────────────────────
    if (txState == STATE_IDLE) {
        static uint32_t lastDraw = 0;
        if (millis() - lastDraw > 200) {
            showIdle(pot);
            lastDraw = millis();
        }

        if (stable && diff && cooldown) {
            StaticJsonDocument<64> doc;
            doc["pot"] = pot;
            String msg;
            serializeJson(doc, msg);

            Serial.printf("[TX] %s\n", msg.c_str());
            ledFlash(3);

            int e = radio.transmit(msg);
            if (e == RADIOLIB_ERR_NONE) {
                activePot = pot;
                lastSentPot = pot;
                lastSendTime = millis();
                rxDeadline = millis() + RESPONSE_TIMEOUT;
                rxFlag = false;
                radio.startReceive();
                txState = STATE_WAITING;
                showWaiting(pot);
            } else {
                Serial.printf("[TX] erreur: %d\n", e);
            }
        }

    // ── WAITING ───────────────────────────────────────────────────────
    } else {
        if (rxFlag) {
            rxFlag = false;
            String resp;
            int e = radio.readData(resp);
            if (e == RADIOLIB_ERR_NONE) {
                resp.trim();
                Serial.printf("[RX] %s\n", resp.c_str());
                showAnswer(resp, activePot);
                digitalWrite(LED_PIN, (activePot > 2048) ? HIGH : LOW);
            } else {
                Serial.printf("[RX] erreur: %d\n", e);
                radio.startReceive();
                return;
            }
            txState = STATE_IDLE;
        }

        if (millis() > rxDeadline) {
            Serial.println("[RX] timeout");
            radio.standby();
            digitalWrite(LED_PIN, LOW);
            txState = STATE_IDLE;
            if (disp) {
                disp->clearBuffer();
                disp->setFont(u8g2_font_fur11_tf);
                disp->drawUTF8(0, 32, "Timeout");
                disp->sendBuffer();
                delay(1000);
            }
        }
    }
}

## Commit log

2026-02-12 Ajout du contrôle de LEDs via interface tactile et port série
2026-02-12 Préparation Labo 2: installation Mosquitto et test WiFi ESP32
